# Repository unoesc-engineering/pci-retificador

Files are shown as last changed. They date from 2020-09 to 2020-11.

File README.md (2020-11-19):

# Retificador em placa de circuito impresso

Este projeto tem como propósito a elaboração de
um protótipo de retificador, a fim de tomar conhecimento da
interação entre componentes com os conhecimentos da
engenharia, principalmente nas disciplinas de eletrônica
analógica, além de conteúdos adjacentes adquiridos no decorrer
do curso até o presente. Os retificadores são responsáveis por
converter uma tensão em corrente alternada para tensão em
corrente contínua. São muito utilizados no cotidiano já que
fazem essa transformação CA-CC, estão presente em eletrônicos
ligados a tomada, já que sua fonte de alimentação fornece
corrente alternada e os equipamentos precisam de corrente
contínua para funcionarem adequadamente. Dessa forma
desenvolvemos um projeto de retificador em que o equipamento
no qual ele será acoplado necessita de baixa potência e alta
confiabilidade.

## Contribuidores

 - Bruna Stofel
 - Bruno Cesca
 - Mateus Calza

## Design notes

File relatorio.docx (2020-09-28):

Retificador PCI

Bruna Stofel
Engenharia de computação
UNOESC – Universidade do Oeste de Santa Catarina
Joaçaba – SC, Brasil
bstofel1@gmail.com

Bruno Cesca
Engenharia de computação
UNOESC – Universidade do Oeste de Santa Catarina
Capinzal – SC, Brasil
brunocesca8@gmail.com
Mateus Calza
Engenharia de computação
UNOESC – Universidade do Oeste de Santa Catarina
Herval D’Oeste – SC, Brasil
calzamateus@gmail.com

Resumo - Este projeto tem como propósito a elaboração de um protótipo de retificador, a fim de tomar conhecimento da interação entre componentes com os conhecimentos da engenharia, principalmente nas disciplinas de eletrônica analógica, além de conteúdos adjacentes adquiridos no decorrer do curso até o presente. Os retificadores são responsáveis por converter uma tensão em corrente alternada para tensão em corrente contínua. São muito utilizados no cotidiano já que fazem essa transformação CA-CC, estão presente em eletrônicos ligados a tomada, já que sua fonte de alimentação fornece corrente alternada e os equipamentos precisam de corrente contínua para funcionarem adequadamente. Dessa forma desenvolvemos um projeto de retificador em que o equipamento no qual ele será acoplado necessita de baixa potência e alta confiabilidade.

Palavras-chave – retificador, pci, eletrônica

# I. Introdução

Deparando-se com dispositivos eletrônicos ligados a uma fonte de alimentação convencional como uma tomada, o primeiro passo para a utilização correta e desenvolvimento de um projeto elétrico é tomar os devidos cuidados com a corrente e tensão que será responsável pela alimentação desse dispositivo. O projeto desenvolvido é responsável por converter uma corrente alternada (ca) em corrente contínua.

A partir de uma fonte de alimentação que gera tensão, os retificadores são responsáveis por fazer a corrente circular no circuito do dispositivo em apenas um sentido. No entanto, a tensão fornecida pela fonte no Brasil varia entre 127V e 220V, esse valor é relativamente muito elevado para a maioria dos eletrônicos, por isso é necessário utilizar um transformador como uma das primeiras etapas do projeto, esse transformador vai baixar a tensão da linha para um nível seguro e adequado para o uso dos diodos.

O circuito de retificador permite a passagem dos ciclos positivos de tensão quando o diodo está em condução, e bloqueia a passagem dos ciclos negativos quando o diodo está em corte. Isso resulta num formato de onda pulsante, somente com os semiciclos positivos senoidais na carga. Devido ao formato desta onda, ou seja, devido à perda dos semiciclos negativos do sinal de entrada, o circuito é denominado retificador de meia-onda. Ao utilizar uma ponte de diodos, pode-se retificar também os semiciclos negativos, resultando num sinal na carga pulsante com o dobro da freqüência do sinal de entrada. Esse é denominado retificador de onda completa.

Usando-se um capacitor em paralelo com a carga, tem-se o efeito de manter a tensão na carga próximo ao valor de pico por mais tempo. Quando a tensão do sinal cai, o capacitor começa a se descarregar, de modo que a tensão nos terminais da carga é superior à tensão vinda da fonte. O diodo retificador entra em corte, até que a tensão vinda da fonte supere novamente a tensão no capacitor.

# II. Fundamentação Teórica

As fontes de tensão são, de forma geral, classificadas em lineares, ferro-ressonantes ou chaveadas. As fontes lineares são compostas por um transformador de entrada operando na frequência da rede, circuitos retificadores, filtro e um regulador de tensão linear [1]. Assim é formada a estrutura básica da placa desenvolvida nesse projeto por simulação.

Inicialmente, a tensão alternada da rede é retificada e filtrada, produzindo uma tensão contínua de valor elevado que é aplicada ao conversor DC/DC. Este conversor, que pode ser isolado ou não isolado, produz uma tensão contínua regulada de saída. Uma amostra desta tensão de saída é comparada com um sinal de valor fixo, produzindo um sinal de erro. Este sinal é utilizado para controlar o tempo de duração da condução da chave e realizar, desta forma, o controle em malha fechada da fonte [2].

O fornecimento de energia elétrica é feito, essencialmente, a partir de uma rede de distribuição em corrente alternada, devido, principalmente, à facilidade de adaptação do nível de tensão por meio de transformadores. Em muitas aplicações, no entanto, a carga alimentada exige uma tensão contínua. A conversão CA-CC é realizada por conversores chamados retificadores. Para níveis de potência baixos os retificadores de diodo conhecidos como retificador não controlado, são uma boa alternativa para realizar a conversão [3].

A forma mais simples de resolver esse problema é utilizar um retificador meia onda para conversão de tensão, no entanto ao utilizar um retificador de onda completa podemos utilizar capacitores de menor valor para o mesmo “ripple” na tensão de saída.

# III. Desenvolvimento

A metodologia utilizada no projeto é a exploratória, buscando conhecimento em artigos e bibliografias para ter uma caracterização do problema e buscar formas para resolvê-lo.

Para ser possível a realização do projeto é necessário o desenvolvimento de alguns passos para identificarmos as funcionalidades e a lógica para o correto funcionamento do circuito retificador.

Partindo do seguinte fluxograma para identificar os passos essenciais do projeto:

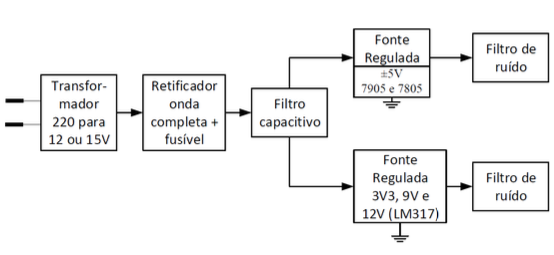
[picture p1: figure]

(Imagem 1 – Fluxograma da fonte CC)

A execução do projeto foi feita em etapas, com a finalidade de dividir os processos necessários para sua concretização, são os seguintes passos:

1. Transformar a tensão de 220V da tomada para 12v
2. Retificador de onda completa
3. filtro capacitivo
4. fonte reguladora
5. filtro de ruído

Os principais componentes utilizados no projeto são os seguintes:

a) LM7805: O regulador de tensão 7805 pode ser usado em fontes de alimentação, carregadores e circuitos em geral, fornecendo uma tensão fixa de 5V na saída. O regulador é um componente de fácil aplicação nos mais variados circuitos, e regula a tensão de entrada, entre 7,5 e 20V, para uma tensão de saída estável de 5V. Pode ser usado com outros componentes eletrônicos para obter valores de tensão e corrente ajustáveis.
b) LM7905: O regulador de tensão 7905 pode ser usado em fontes de alimentação, carregadores e circuitos em geral, fornecendo uma tensão fixa de -5V na saída.O regulador de tensão é um componente de fácil aplicação nos mais variados circuitos, e regula a tensão de entrada negativa entre -7 e -25VDC, para uma tensão de saída estável de -5V. Pode ser usado com outros componentes eletrônicos para obter valores de tensão e corrente ajustáveis.
c) LM317: O CI regulador de tensão LM317T é um componente muito utilizado em fontes de alimentação, suportando correntes de até 1.5A com tensão entre 1.2 e 37V. O LM317 é muito simples de utilizar, exigindo apenas 2 resistores externos para regular a tensão de saída.
d) Demais componentes segue na tabela abaixo:

Componente | CI
CAPACITOR 100uF | 6
CI 7905 | 1
CI LM 317T | 1
CI 7805 | 1
VSINE | 1
FUSE | 1
B40K420 | 1
DF10M | 1
RES 330 ohm | 3
RES 3800 ohm | 1
RES 3900 ohm | 1
RES 100 ohm | 1
RES 1000 ohm | 1
RES 1800 ohm | 1
RES 500 ohm | 1
SW-ROT-3 | 1
TRAN-2P3S | 1

Tabela 1 – componentes

Já no desenvolvimento do projeto, inicialmente calculamos a tensão de entrada sobre a tensão de saída utilizando a fórmula a seguir que nos deu o resultado de 168.0555556H.

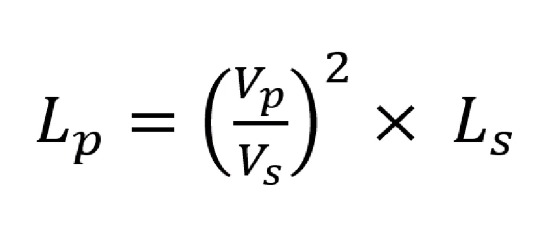
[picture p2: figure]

(Imagem 2 – fórmula)

A partir do cálculo precisamos converter a tensão de 220V da tomada para 12V, a fonte de energia do nosso circuito. Nessa parte já adicionamos o fusível + varistor para a segurança do circuito.

Para calcular a tensão de entrada no transformador utilizamos ( √2* 220 = 311 V ).

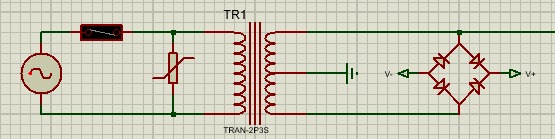
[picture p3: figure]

(Imagem 3 – Conversão de tensão)

Para o retificador de onda completa utilizamos os 4 diodos. Com o LM317 regulamos a fonte para 3V3, 9V e 12V conforme o circuito a seguir.

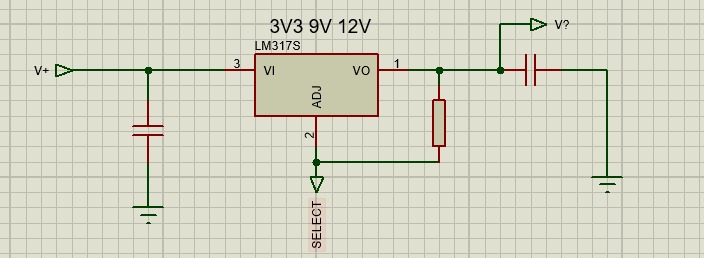
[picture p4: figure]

(Imagem 4 – circuito com LM317)

Desenvolvemos também um circuito auxiliar de seleção de chaves, assim é possível escolher a tensão desejada.

(Imagem 5 – dip switches)

Utilizando o LM7805 no circuito para ter uma tensão de saída equivalente a +5V.

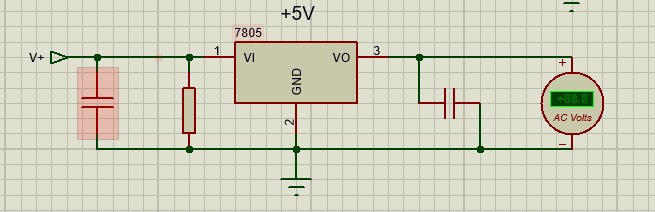
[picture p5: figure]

(Imagem 6 – LM7805)

E o LM7905 para tensão de saída de -5V.

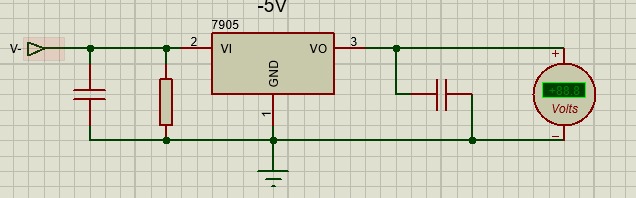
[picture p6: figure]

(Imagem 7 – LM7905)

Fizemos a medição com o osciloscópio da onda com sinal não retificado e inicialmente ainda sem o filtro capacitivo e sem tratamento representado pela onda amarela. Já a segunda medição é a onda completa com tratamento.

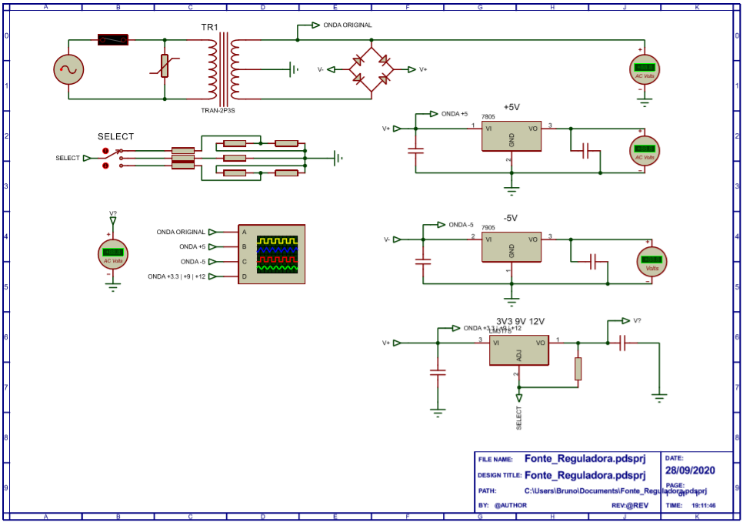
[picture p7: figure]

(Imagem 7.1 – Circuito Completo)

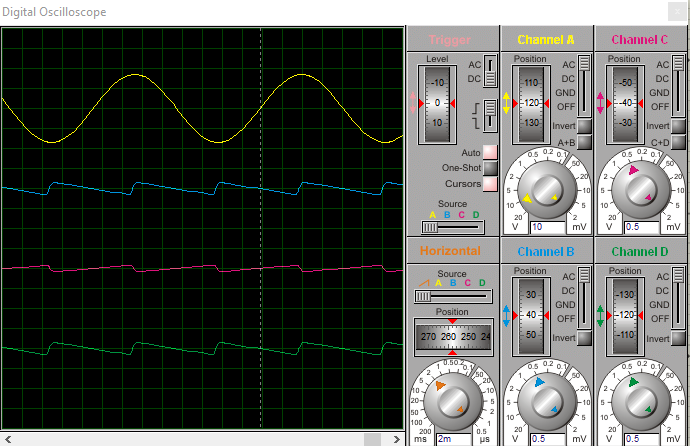
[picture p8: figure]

(Imagem 8 – Medições com osciloscópio)

Para fazer o modelo para uma placa de circuito impresso (PCI) foi utilizado o software Eagle. O plano esquemático foi reproduzido baseado na simulação, com algumas adequações.

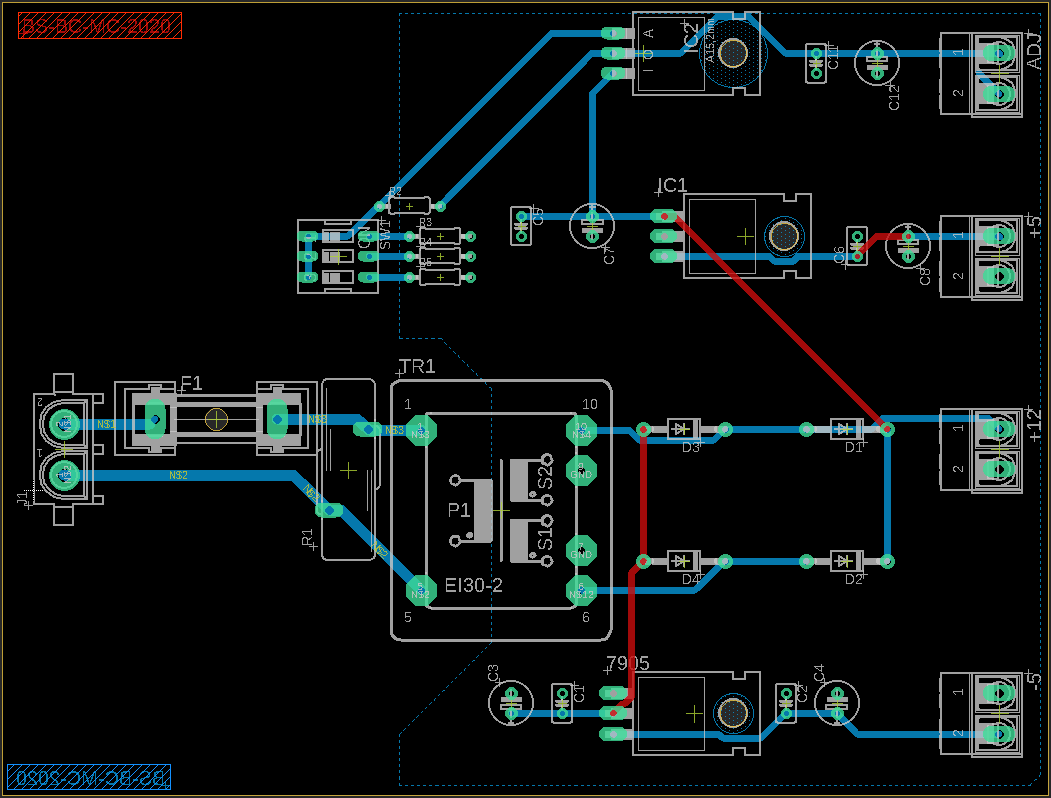
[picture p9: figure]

(Imagem 9 – Placa de circuito impresso)

Dentre as técnicas utilizadas, temos a malha para GND, interconectando as trilhas deste tipo simplificando a placa, capaz até de reduzir ruídos. Neste caso, esta malha foi mantida distante da corrente alternada, conforme a imagem:

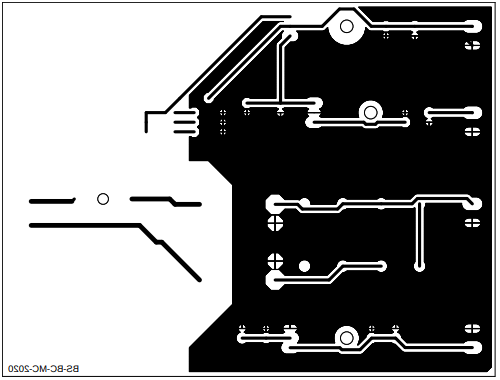
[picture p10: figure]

(Imagem 10 – Lado de baixo da placa de circuito impresso, monocromático)

# IV. Resultados

Os resultados do desenvolvimento do projeto foram no geral satisfatórios, tivemos problemas apenas no circuito seletor do LM317 onde não foi possível ajustar com precisão a tensão de 9V devido o valor da resistência que não foi preciso.

# V. Conclusão

Neste projeto para concretizar a realização e adequado funcionamento do protótipo estabelecido, foram realizados diversos testes com componentes e equipamentos a fim de encontrar a melhor maneira de estrutura-lo com os conhecimentos e recursos da equipe, buscando agregar o máximo de conhecimento e otimização dos processos no tempo definido para sua execução.

Analisando as propriedades de cada componente e buscando informações sobre seu uso e aplicações realizamos os devidos cálculos e montamos o projeto de acordo com os resultados esperados e o comportamento do mesmo como um todo. Assim concluímos que colocando a teoria em prática, os cálculos a maioria deles saíram como o esperado, apenas alguns detalhes não tão precisos no momento de montar os circuitos.

##### Referências

[1] M. Brumatti. Eletrônica de Potência, [S.l.]: Centro Federal de Educação Tecnológica do Espírito Santo, Serra - ES, 2005.
[2] C. H. G. Treviso, Apostila: Eletrônica de potência. Universidade Estadual de Londrina, Londrina - PR, 2016.
[3] J. A. Pomilio. Disponível em: http://www.dsce.fee.unicamp.br/~antenor/pdffiles/eltpot/cap3.pdf. Acessado em: Outubro, 25, 2020.

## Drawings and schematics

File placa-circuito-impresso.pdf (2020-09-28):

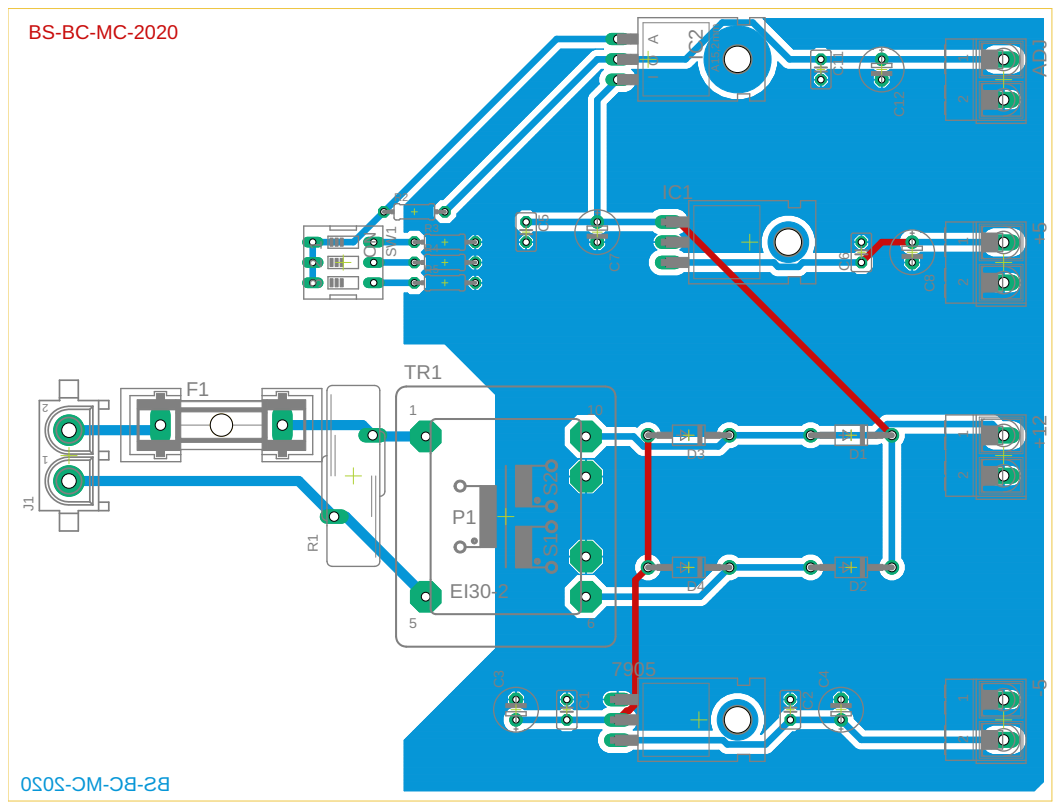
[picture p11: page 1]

0202- CM- CB- SB BS-BC-MC-2020 1 2 1 2 1 2 1 2 A15,2mm 12 P1 S1 S2 EI30-2 15 610 O I A 1ON 2 3 +12 +5 -5 7905 ADJ C1 C11 C12 C2 C3 C4 C5 C6 C7 C8 D1 D2 D3 D4 F1 IC1 IC2 J1 R1 R2 R3 R4 R5 SW1 TR1

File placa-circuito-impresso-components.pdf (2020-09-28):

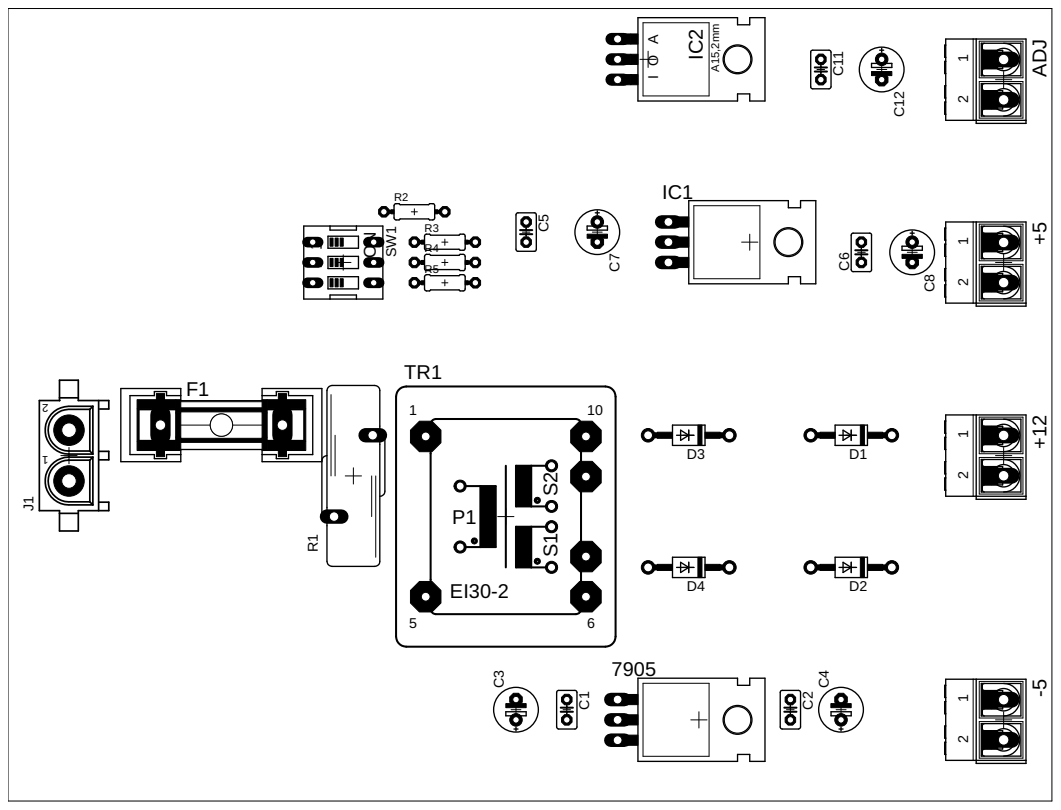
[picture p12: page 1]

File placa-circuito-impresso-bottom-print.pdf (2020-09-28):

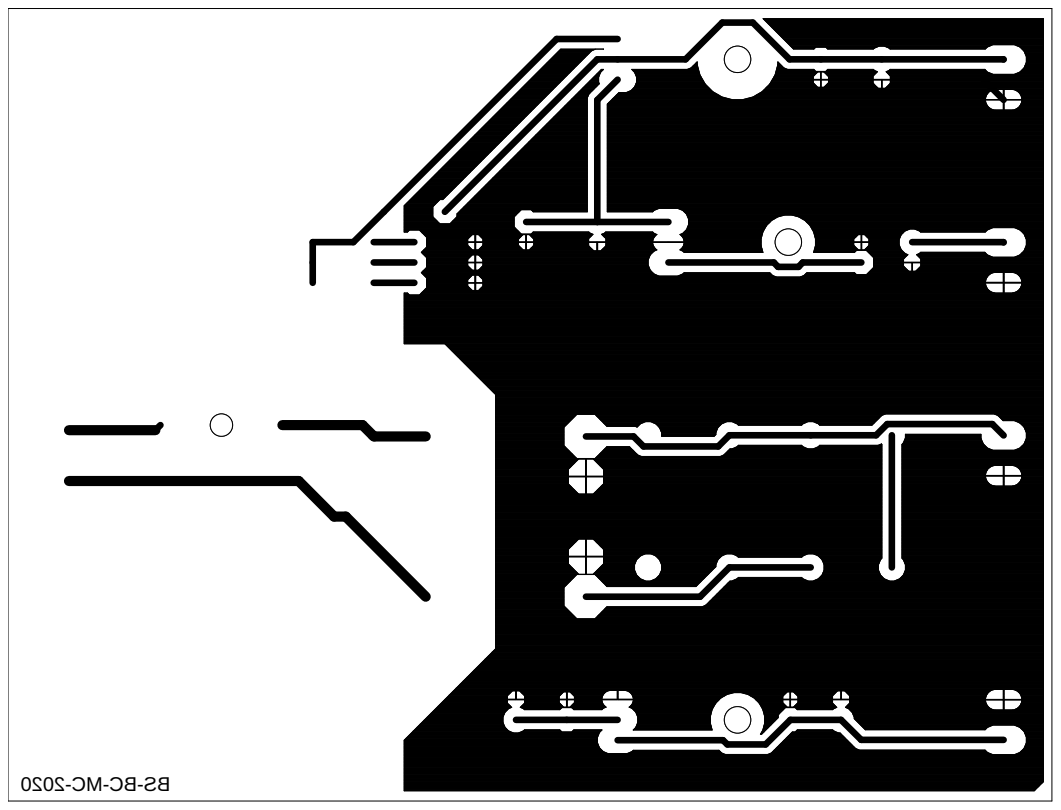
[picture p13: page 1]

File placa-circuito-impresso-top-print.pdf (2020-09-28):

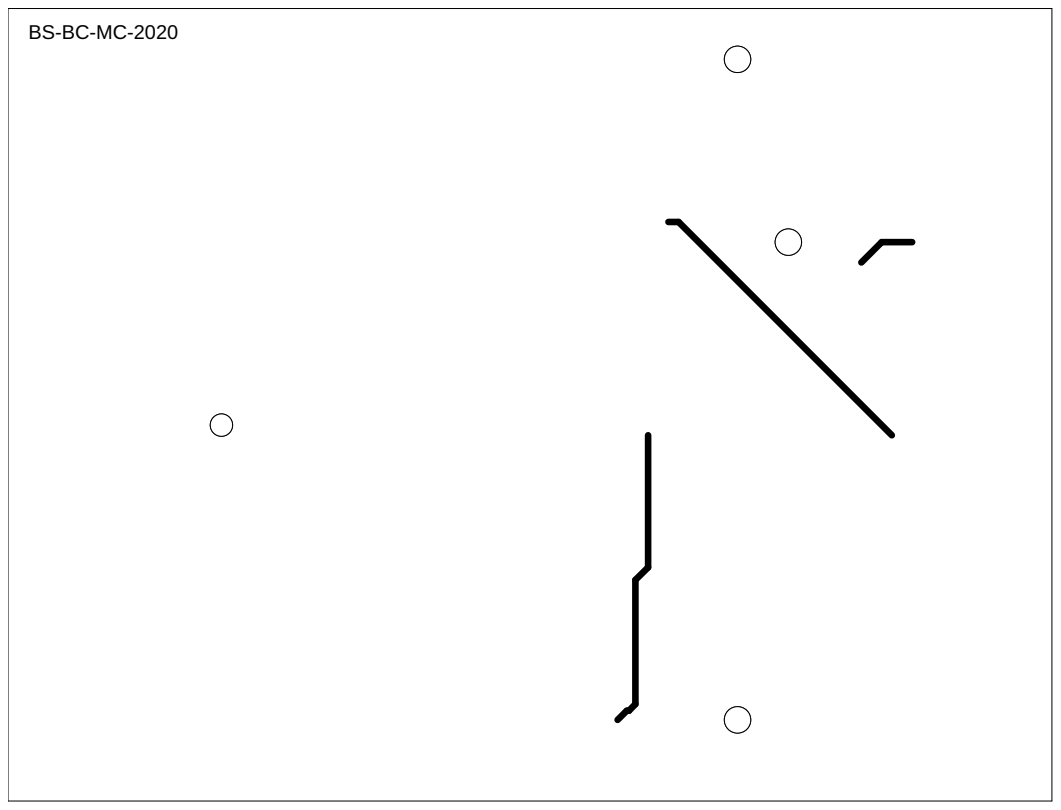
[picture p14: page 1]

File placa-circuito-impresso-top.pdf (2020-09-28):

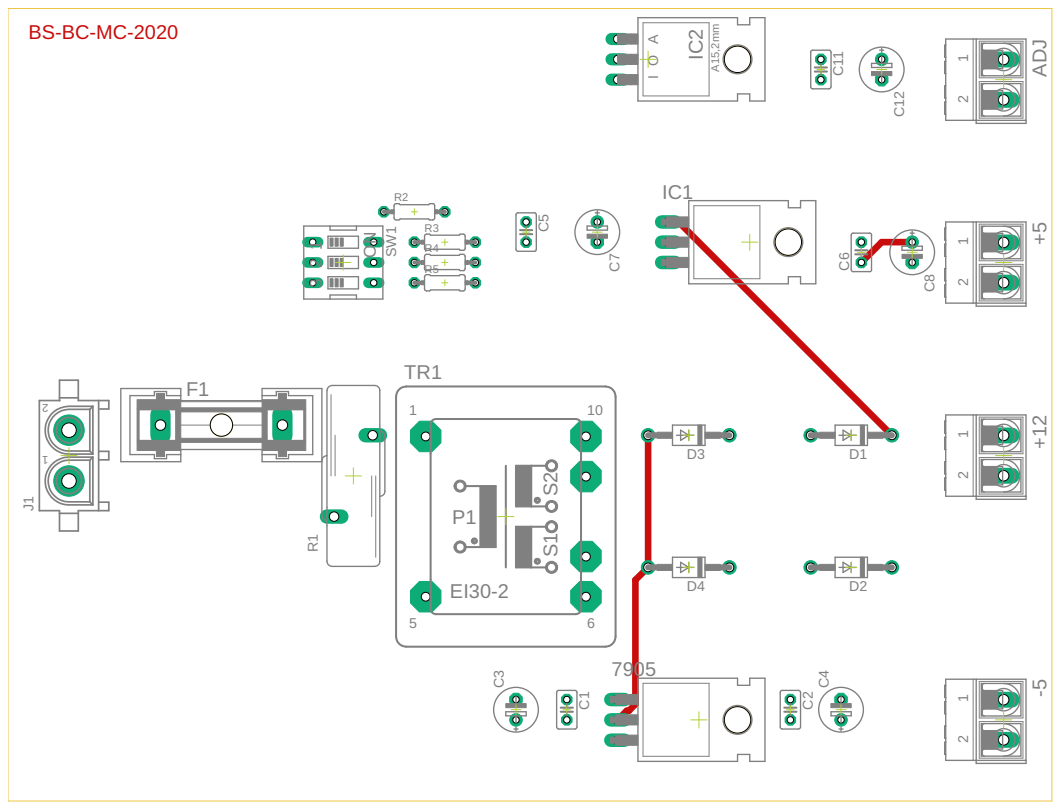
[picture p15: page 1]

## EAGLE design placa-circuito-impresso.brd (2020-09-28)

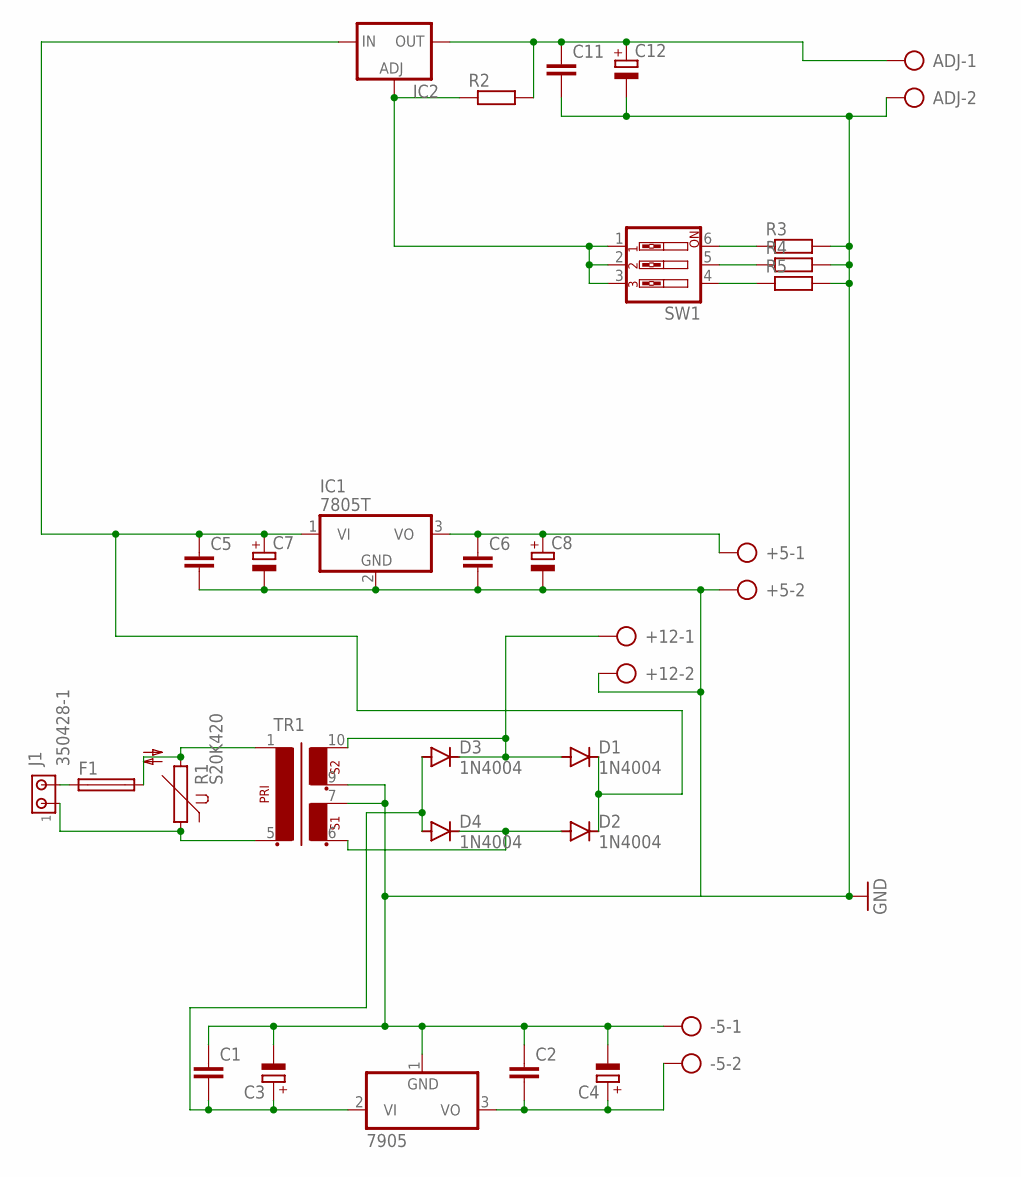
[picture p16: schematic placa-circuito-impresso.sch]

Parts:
7905: 7905T; TO220H
+5, +12: AK500/2-H
-5: AK500/2-H
ADJ: AK500/2-H
C1, C2, C5, C6, C11: C-EU025-025X050; C025-025X050
C3, C4, C7, C8, C12: CPOL-EUE2,5-6E; E2,5-6E
D1, D2, D3, D4: 1N4004; DO41-10
F1: GSH15
IC1: 7805T; TO220H
IC2: LM317TL; 317TL
J1: 350428-1
R1: S20K420
R2, R3, R4, R5: R-EU_0204/7; 0204/7
SW1: SW_DIP-3; EDG-03
TR1: EI30-2

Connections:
GND: 7905.1 (GND), +5.2, +12.2, -5.1, ADJ.2, C1.1, C2.1, C3.-, C4.-, C5.2, C6.2, C7.-, C8.-, C11.2, C12.-, IC1.2 (GND), R3.2, R4.2, R5.2, TR1.7 (4), TR1.9 (5)
unnamed: F1.1, J1.2
unnamed: J1.1, R1.1, TR1.5 (2)
unnamed: F1.2, R1.2, TR1.1
unnamed: +12.1, D1.A, D3.C, TR1.10 (6)
unnamed: R3.1, SW1.6
unnamed: 7905.2 (VI), C1.2, C3.+, D3.A, D4.A
unnamed: R4.1, SW1.5
unnamed: 7905.3 (VO), -5.2, C2.2, C4.+
unnamed: +5.1, C6.1, C8.+, IC1.3 (VO)
unnamed: C5.1, C7.+, D1.C, D2.C, IC1.1 (VI), IC2.3 (IN)
unnamed: ADJ.1, C11.1, C12.+, IC2.2 (OUT), R2.2
unnamed: D2.A, D4.C, TR1.6 (3)
unnamed: IC2.1 (ADJ), R2.1, SW1.1, SW1.2, SW1.3
unnamed: R5.1, SW1.4

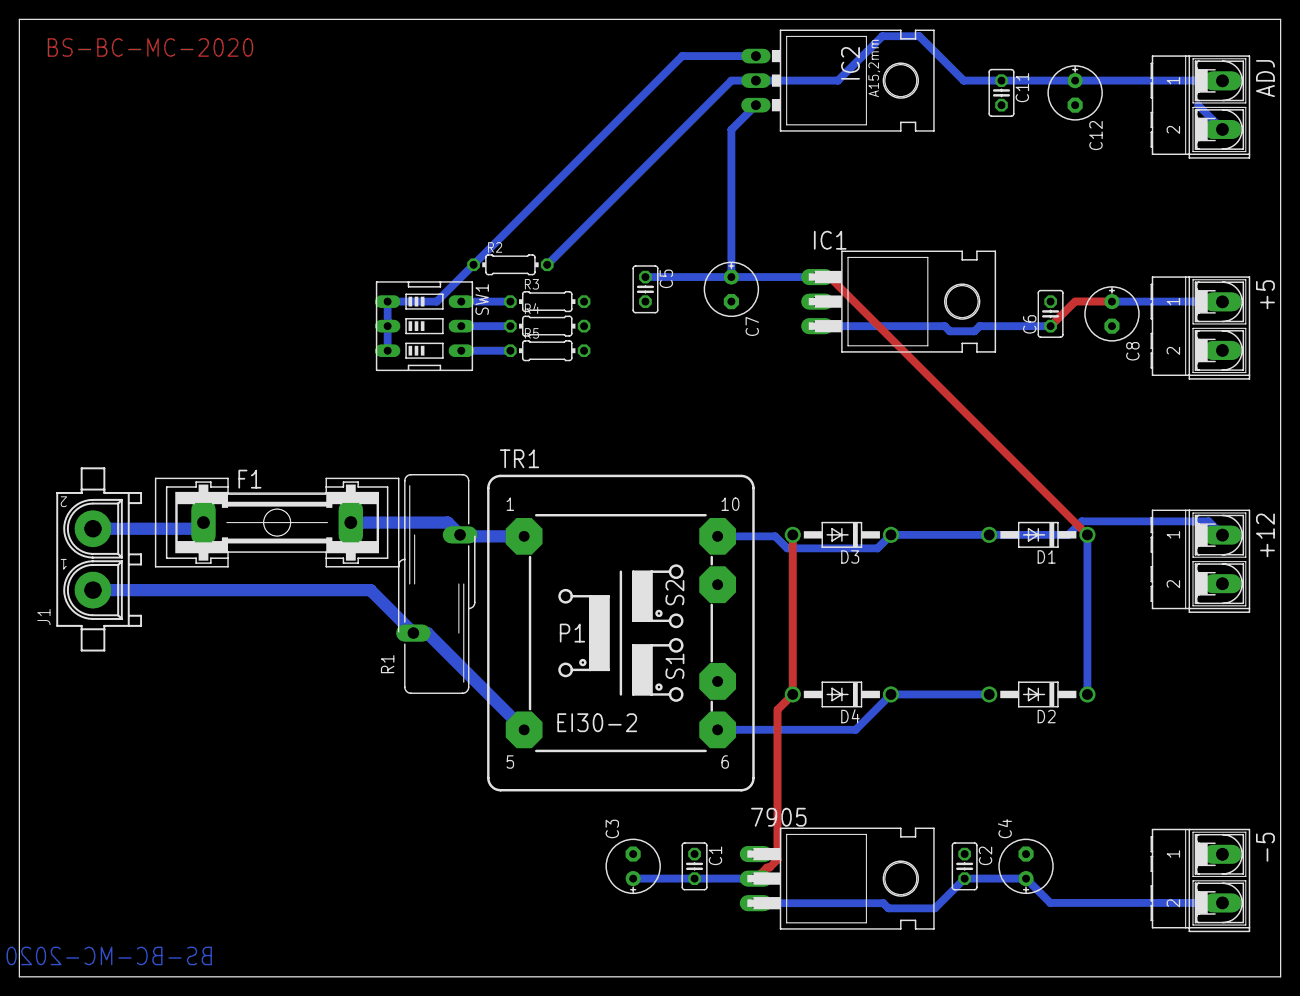
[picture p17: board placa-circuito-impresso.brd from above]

Board: 2 copper layers, 130.5 x 99.1 mm, 30 parts (0 on the bottom side), 15 nets.

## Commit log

2020-09-28 Atualizando espessura das linhas e reorganizando
    [board.brd]
2020-09-28 Linhas automáticas
    [board.brd, board.sch]
2020-09-28 Atualizações na board
    [board.brd]
2020-09-28 Reposicionando na board
    [board.brd, board.sch]
2020-09-28 Ajustes na board
    [board.brd]
2020-09-28 Malha de GND e impressões.
    [board.brd]
2020-09-28 Reorganizando projeto.
    [placa-circuito-impresso.brd, placa-circuito-impresso.sch]
